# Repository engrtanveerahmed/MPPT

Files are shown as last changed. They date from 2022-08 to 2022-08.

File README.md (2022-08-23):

# Maximum Power Point Tracking (MPPT)

## Introduction
We know that sun light is varriable during day some time is low some time it's intensity is high specially at mid of day its intensity is high due to this our solar pannel gives varriable voltages we intensity is high our normal solar pannel 12 voltes rated  gives 14or 15 voltages and if it is connected to 12v rated bettery this extra voltages is really hazerd for our bettry in ordr to remove this hazerd we design Maximun power point trackin solar charge controller (MPPT).

## Design requirements
In todays world design in project play inportant it requires to main key parameters one is we can carry it any where easily number two it is eye catching, in order to do we made design on autocade and also we are blessed with fablab that contain 3D printer with help of that we made our 3D design

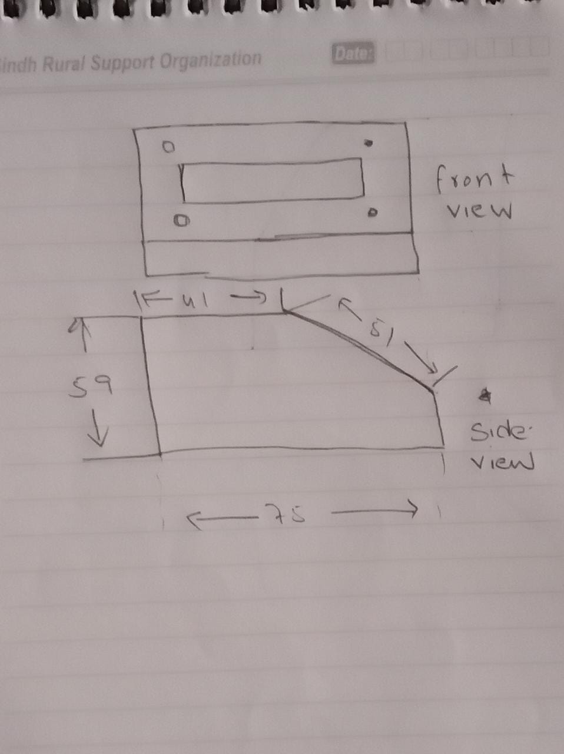
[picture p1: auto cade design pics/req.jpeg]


## Project excuting plan
We have distribute our task in to two member so that beacause in short time we have alot of work to do bellow chart contain our flow of doing work. 

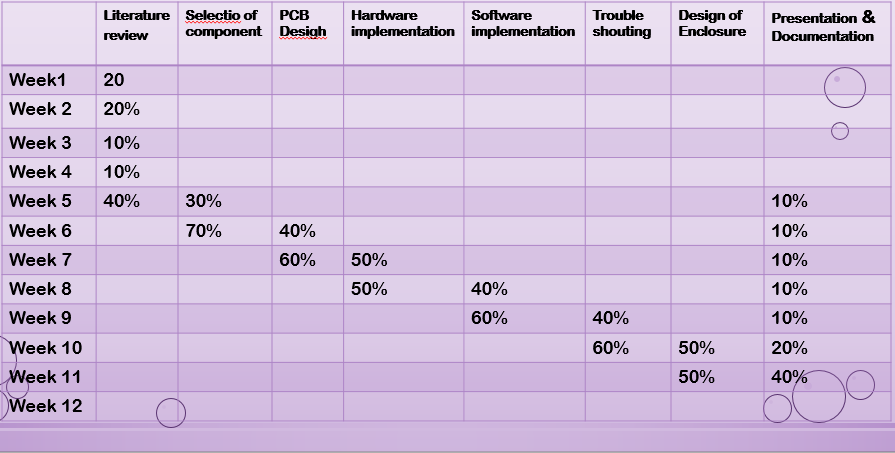
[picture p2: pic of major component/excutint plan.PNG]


## Destributinsion of tasks

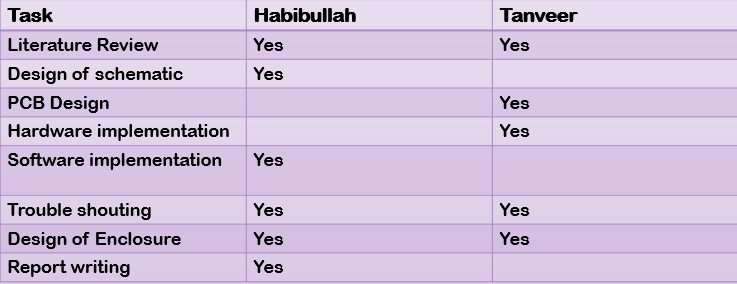
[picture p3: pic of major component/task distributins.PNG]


## Higher level Diagram

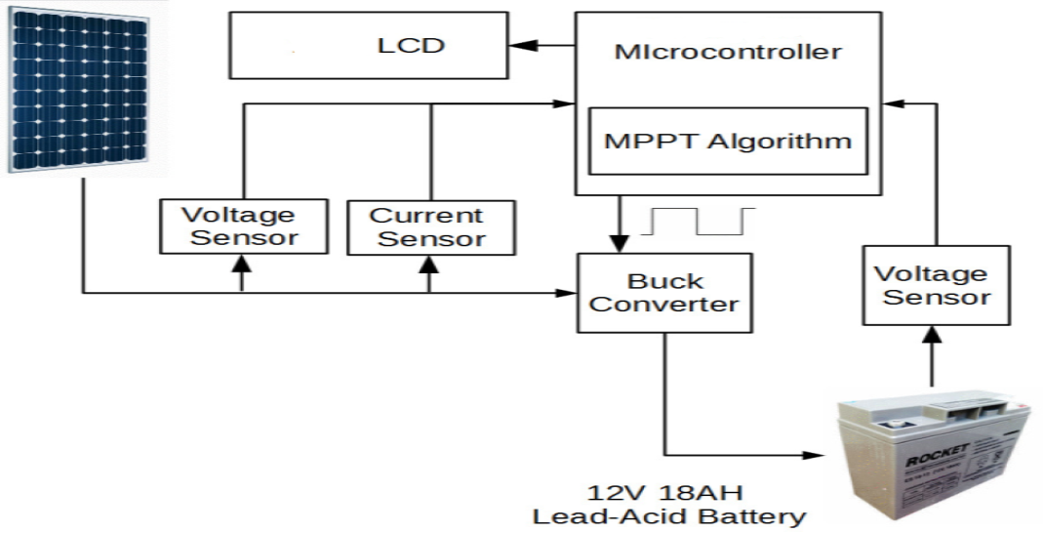
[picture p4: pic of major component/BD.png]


## Description of Principle of Operations
MPPT Min work is to gives stable (12)voltageg at out put this work (step down) is done by the buck converter, at in put and out we used voltage and current sensior; voltages divder circuit at input and output Which sensed voltages developed on the input and gives it to an analogue pin of microcontroller. also a current sense amplifier is attached using a shunt resistor on the main input section. There is also a voltage divider circuit on the output section where the battery is connected. A current sense amplifier is used on the output section as well. These all values are fed to the microcontroller. Depending upon these values, microcontroller decides about the PWM signal fed to the Half-Bridge Mosfet Driver IC. this IC takes input as a PWM signal and switches the MOSFETs with a very high speed. The Buck converter acts according to the decission made by microcontroller depending upon the input and output currents and voltages.

## Bill of material
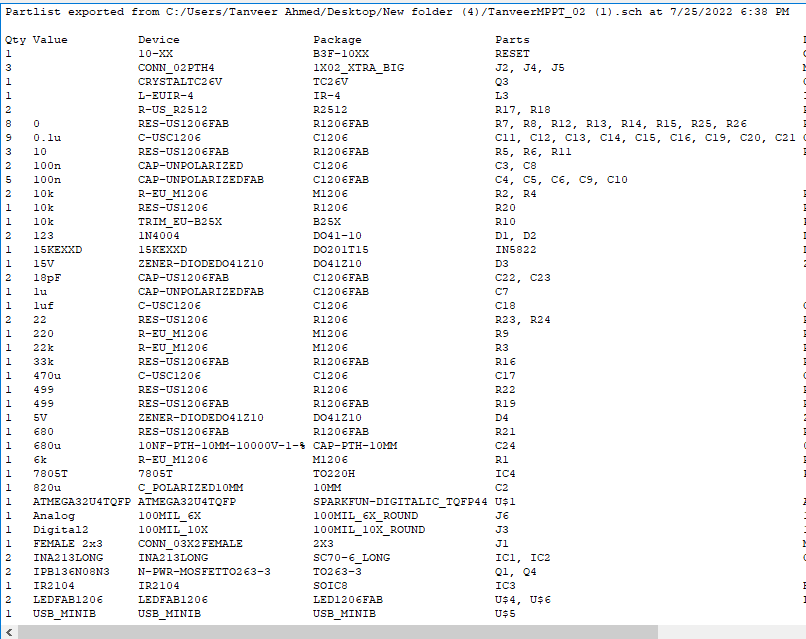
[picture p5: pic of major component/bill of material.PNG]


## Desciption of Major Components of project
##### Microcontroller:

The low-power Microchip 8-bit AVR RISC-based microcontroller featuring 32KB self-programming flash program memory, 2.5KB SRAM, 1KB EEPROM, USB 2.0 full-speed/low speed device, 12-channel 10-bit A/D-converter, and JTAG interface for on-chip-debug. The device achieves up to 16 MIPS throughput at 16 MHz. 2.7 - 5.5 Volt operation. We have used this microcontroller because of its lower consemption and usb support. its features helped us to replace arduino with this microcintroller in project.
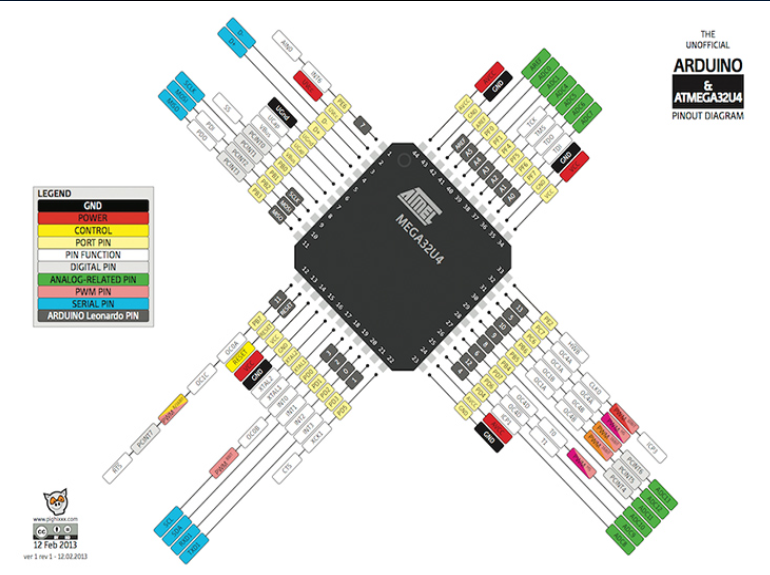
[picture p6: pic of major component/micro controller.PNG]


###### USB mini:
The small USB is used in digitil devices like digital cameras, external hard drives, USB hubs and other equipment. Mini USB is much smaller than USB Type A and B but twice as thick as Micro USB. We have used this componant as we could burn our code easily on the microcontroller.

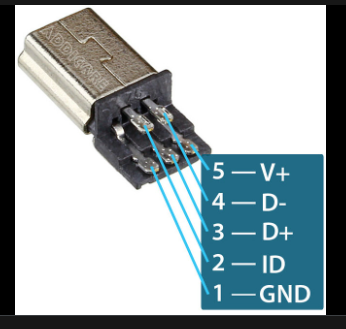
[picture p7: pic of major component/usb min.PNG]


##### INA213 (Current sense amplifier):
The INA21x are voltage-output, current-shunt monitors (also called current-sense amplifiers) that are commonly used for overcurrent protection, precision-current measurement for system optimization, or in closed-loop feedback circuits. This series of devices can sense drops across shunts at common-mode voltages from 0.3 V to 26 V, independent of the supply voltage. Six fixed gains are available: 50 V/V, 75 V/V, 100 V/V, 200 V/V, 500 V/V, or 1000 V/V. The low offset of the zero-drift architecture enables current sensing with maximum drops across the shunt as low as 10-mV full-scale. These devices operate from a single 2.7-V to 26-V power supply, drawing a maximum of 100 uA of supply current. All versions are specified over the extended operating temperature range (40°C to +125°C), and offered in SC70 and UQFN packages. We have used this componant as to sense the input and output voltage/current to track the working of the MPPT.

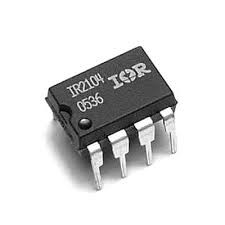
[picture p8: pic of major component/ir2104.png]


##### IR2104 (Half-bridge):
The discrete Half-bridge driver based on IR2104 gate driver IC and low impedance high current N channel IRFP4368 MOSFETS , The IR2104 is a high voltage, high speed power MOSFET driver with independent high and low side referenced output channels. We have used this componant to derive the mosfets.



##### Schottky Diode :
The Schottky Diode is a type of semiconductor diode which have the advantage that their forward voltage drop is substantially less than that of the conventional silicon pn-junction diode. Schottky diodes have many useful applications from rectification, signal conditioning and switching, through to TTL and CMOS logic gates due mainly to their low power and fast switching speeds.

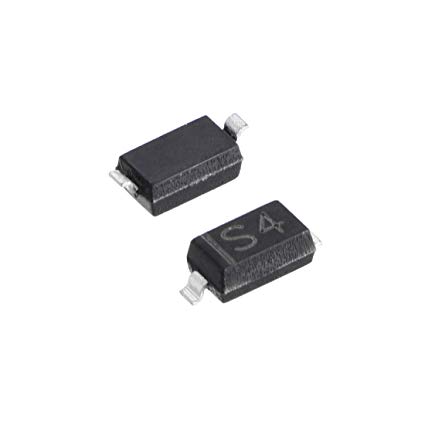
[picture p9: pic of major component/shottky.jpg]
)

##### IPB136n08n3 (PWR-MOSFET):
These are ideal for high frequency switching. Optimized technology for DC/DC converters. Excellent gate charge x R product N-channel, normal level. 100% avalanche tested. Pb-free plating; RoHs compliant.

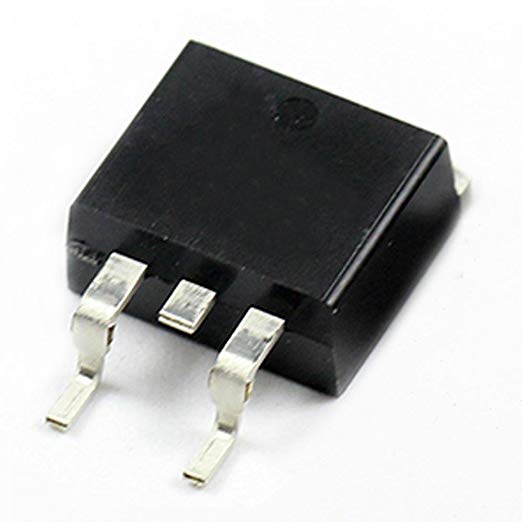
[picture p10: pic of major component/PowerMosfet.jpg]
)

Shunt Resistors:
Shunt resistors are used with current sense amplifier to sense the current.

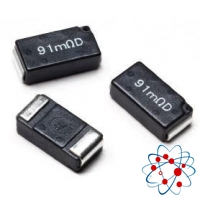
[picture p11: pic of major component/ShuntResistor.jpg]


##### Voltage Regulator LM7805:
We are using this voltage regulator because the input voltage is 12 voltages and our microcintroller and some other componants run on 5V so its is regulating the voltages. It is easily available for use.

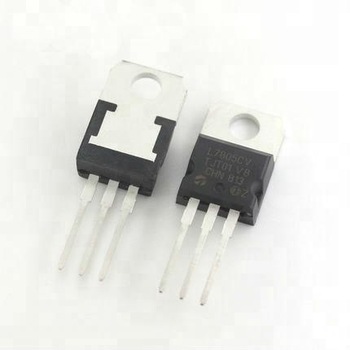
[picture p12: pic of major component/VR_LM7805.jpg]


##### Zener Diode::
We are using zener diode if our input voltage increases from the circuit limitations, it will directly ground the voltages.

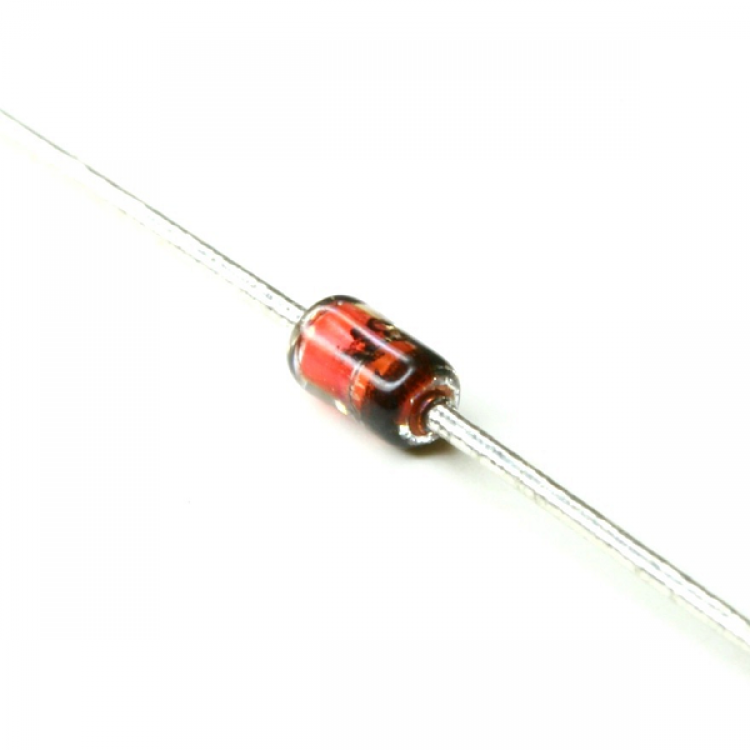
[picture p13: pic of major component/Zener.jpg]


###### Connectivity to components (Protocol)
As we have used Atmega32U4 microcontroller, which has the support to connect a USB, so we are using Universal serial bus for the connectivity of our board with PC to burn the code into it.
## Electrical Schematic
The schematic diagram is taken from the Eagle file we have developed for our final PCB:

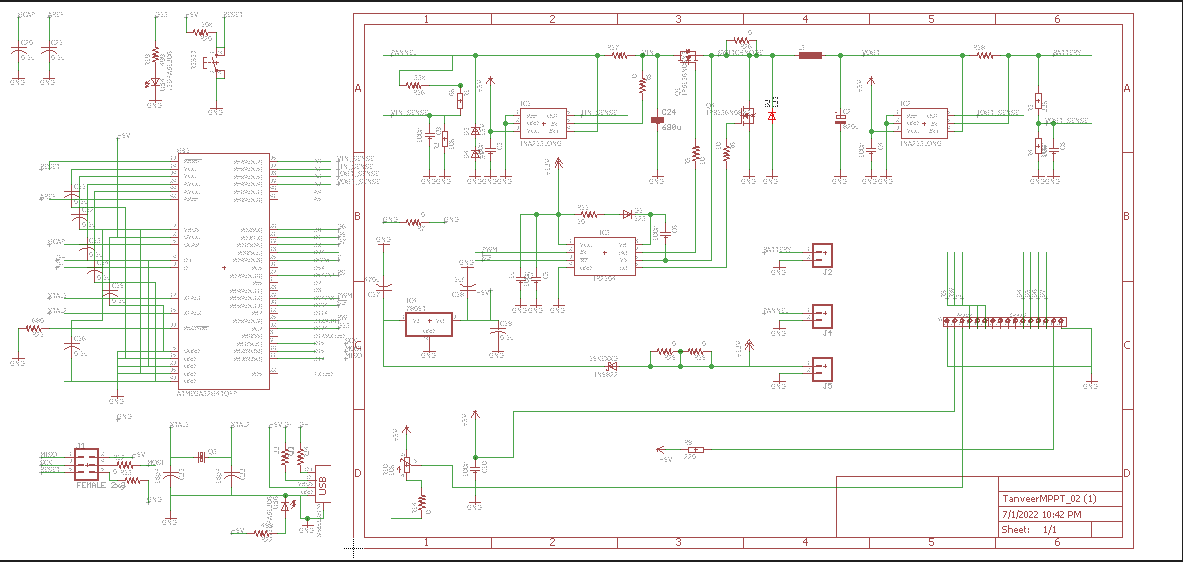
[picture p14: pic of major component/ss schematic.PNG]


## Brief Description of Schematic
Here we define our project more clearily.

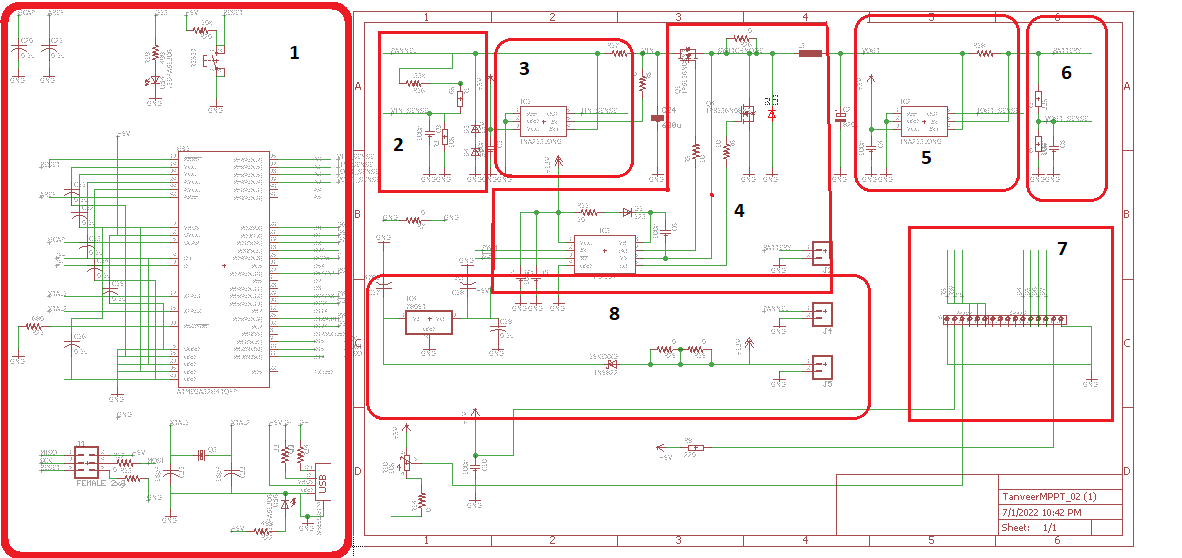
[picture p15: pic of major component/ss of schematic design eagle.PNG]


##### Microcontroller and its required components:
The microcontroller is the key component of this whole circuit as it is making decissions on the basis of values it is receiving. the components attached with microcontroller in "1" are chosen according to the Arduino Leonardo which uses the same Microcontroller. An ICSP header is also connected to burn the boadloader on to the microcontroller. The connection of a USB MINI are also made with the microcontroller.

##### Input Voltage Divider Circuit:
This circuit divides the input voltage to such a level in which microcontroller can sense it because if we attach the microcontroller directly, it cannot bear the voltage and will burnout intantly. So we have to reduce the voltage to such a level which can be given to microcontroller. We used a 39kiloohm resistor and a 10 kilo ohm resistor to make the ratio appropriate. Also two zener voltages are connected in parallel for we want input voltage not more than a certain value.
##### Input Current Sense Amplifier:
INA213, a current sense amplifier is connected here to sense the input current. The shunt resistor helps this IC to sense the current and then this IC gives output to the Microcontroller which then displays it on the LCD.

##### Half Bridge Driver IC and Buck Converter:
The IR2104, a half bridge MOSFET driver takes input of PWM signal from the microcontroller and then performs the switching of the MOSFETs. Hence controlling the output current and voltage.

##### Output Current Sense Amplifier:
It works on the same principle as the input current sense amplifier.

##### Output Voltage Regulator:
Volatge regulator is developed here for the same reason, the only difference is the voltage for division. Here the voltage is 12V. So, we connected a 22 kilo-ohm resistor in series with a 10 kilo-ohm resistor.

##### LCD connectors:
these connectors are attached for the display which will be mounted on the casing.

##### Power Headers and Voltage Regulator:
The three headers for 12 volts Supply(on which the board will operate), Panel(to take input from solar panel) and Output(for the output voltage taken from the circuitry ). The voltage regulator is connected because we are using 12V supply on which the IC IR2104 operates but all other ICs need 5V to operate so we are using this LM7805 for this purpose.

## PCB Layout

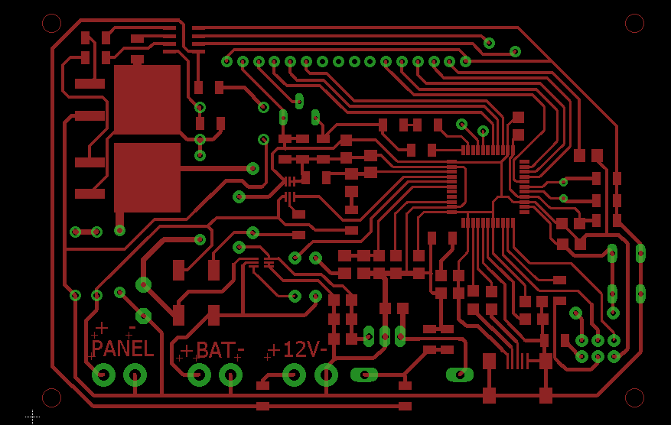
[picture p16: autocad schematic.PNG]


We used Eagle software to develop the PCB for our project and we created the layouts in .PNG formats as the Milling Machine available in Fablab needs picture format for its processing. Following is the final PCB layout:

## Challenges While Routing
Whille routing the PCB it consumed a lot of out time because the circuit we were following used a separate board for microcontroller but our aim was to embed both the circuit on a single layer, making it more compact. This came with lots of hurdles while routing, we used few zero ohm resitor to overcome routing issues and at the end developed a lot more compact circuit after tens of attempts.

## Bill of Material on taped on a Paper
Following is the Picture of the components taken from the FabLab



## Picture of Clean Printed Circuit Board
For fabrication of our PCB, we used SRM-20(Rolland's mills) machine. It needs a monochrome picture for its processing. the monochrome picture we took from Eagle software were then uploaded to the "Fab-Modules.org" and then we generated the ".rml" files needed for SRM-20 to process the milling.

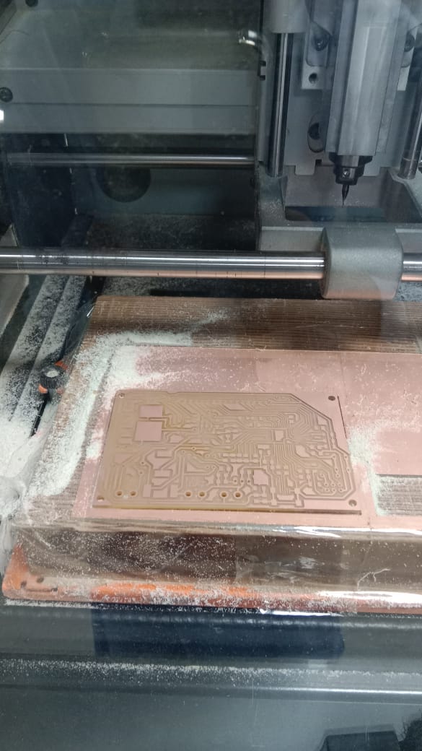
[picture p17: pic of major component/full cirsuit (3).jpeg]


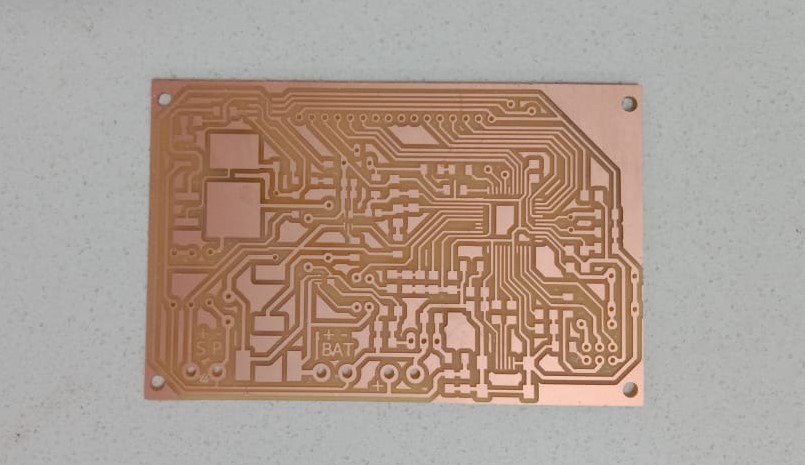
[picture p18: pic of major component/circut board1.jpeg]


## Picture of Populated Circuited Board
After fully soldering teh components, our board looked like this:

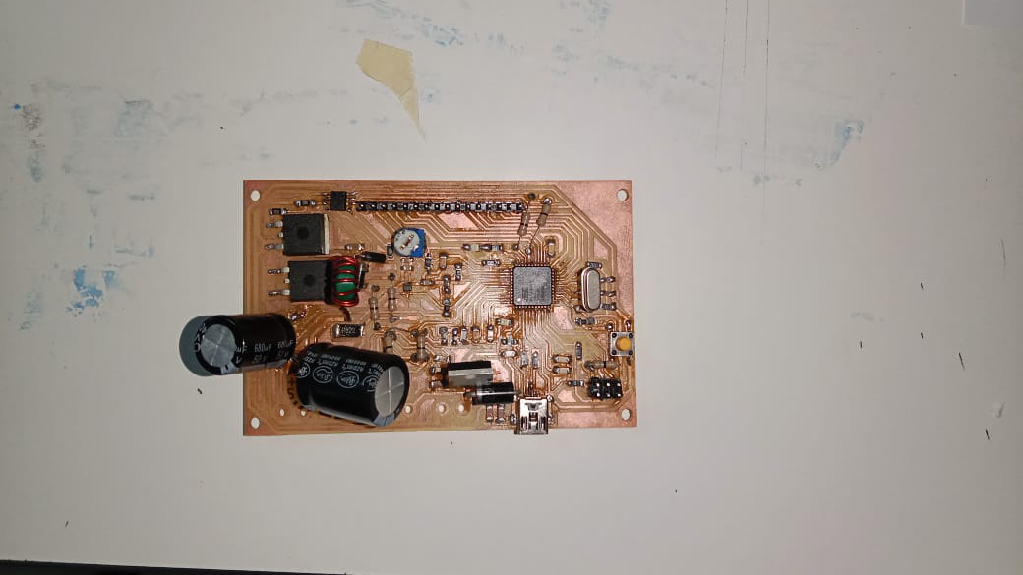
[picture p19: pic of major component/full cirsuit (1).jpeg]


## Procedure adopted to burn Bootloader
To burn the boot loader on to the microcontroller, we used ICSP header and arduino IDE. we burnt the bootloader of Arduino leonardo onto the ATmega32U4. For this we followed the following steps:
1. connetcing th board with PC through ICSP header and a USB mini cable for further burning the test code.
2. selecting the board through "Tools" menu.
3. in tools, further going to submenu "Select Board".
4. selecting "Arduino Leonardo".
5. again going to "tools" menu and then selecting the submenu "Port" and then select the port on which ICSP is connected.
6. again going to another submenu "Programmer" and selecting "AVRISP mkll" .
7. last step is to select the last most option of "burn the bootloader".
8. wait for few minutes till it shows the message on status bar as "Done burning Bootloader.".

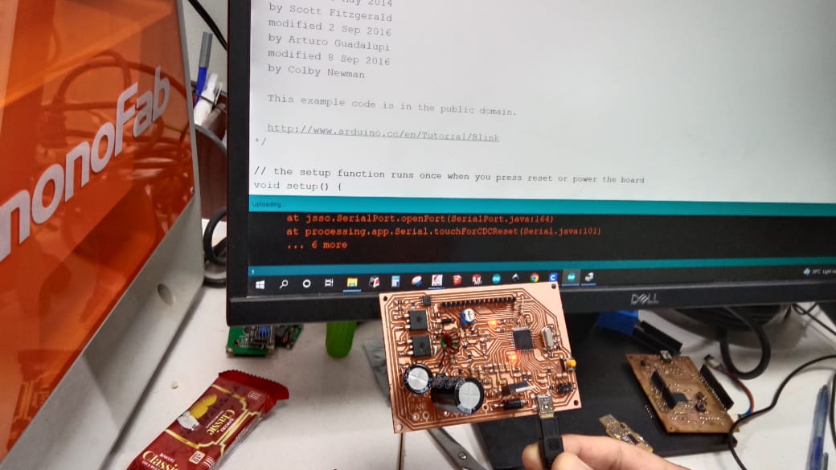
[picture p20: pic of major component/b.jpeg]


## Picture of successfully operating circuit

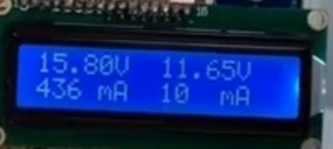
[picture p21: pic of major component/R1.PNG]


## Picture of fully assembled System

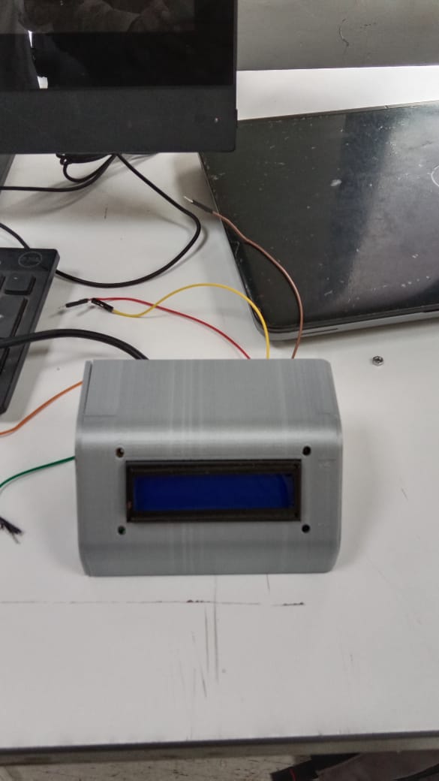
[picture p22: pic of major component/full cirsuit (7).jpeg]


## The FlowChart of our software design

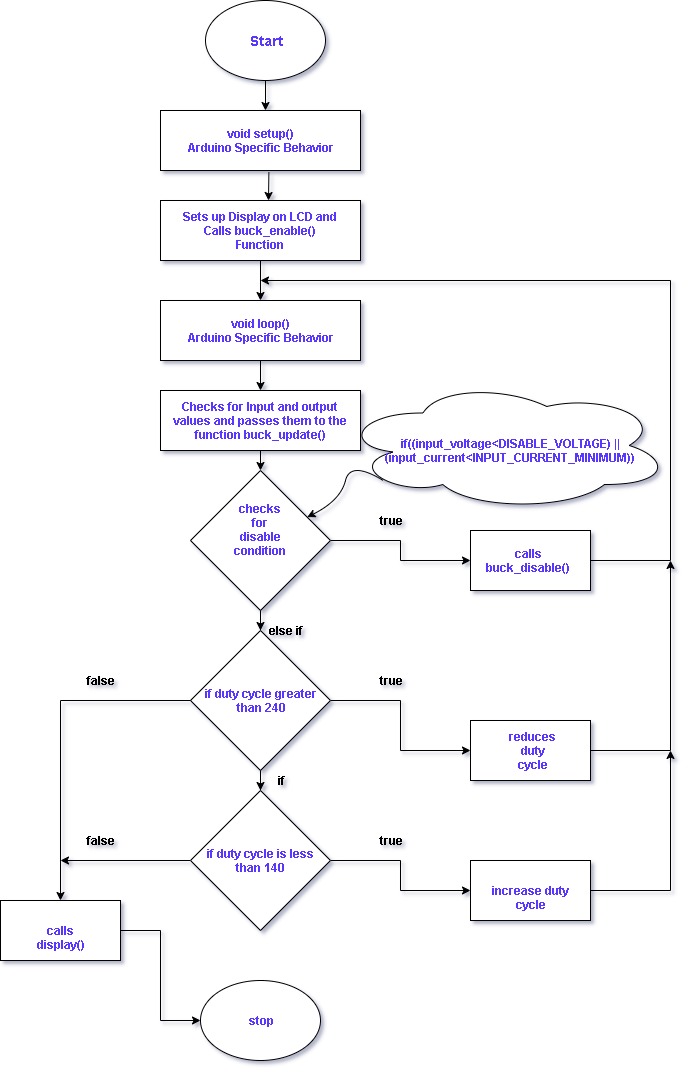
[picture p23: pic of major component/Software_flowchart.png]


## Main Functions of the code
##### buck_setup() Function::
This function is designed to set up the timer to generate PWM signal. It initializes the timer with the desired duty cycle to set the circuit up.
##### buck_enable() Function:
This method is written so to enable the clock source and then turns on the Half bridge driver through PWM signal.
##### buck_disable() Function:
TThis functtion turns off the clock source and sets the duty cycle of PWM signal to zero.
##### buck_duty(unit8_t duty) Function:
This function checks the duty cycle of the and stes it to the appropriate value for the operation of the Buck converter. it Arranges the duty cycle to an optimum level.
##### write_display() Function:
This function is utlized to write on the LCD. it tfakes values from several values and displays them along with some text on the LCD.
##### read_values() Function:
This function takes the values from the volatge divider circuits and current sense amplifiers and sets them correctly after callibration.
##### buck_update() Function:
This method is the key function in the code which calls some of the above functions and updates the duty cucle accordingly.

## Challenges faced while coding
The major problem we faced during the coding for this project was configuring the timer for generatng PWM signal. We tried to configure different available timers using different PWM pins on the board. First we configured timer1 using PWM pin 9, but this timer was a 16 bit timer which brought a lot of problems because our major calculations were based on the 8 bit timer. so after struggling a lot we obtained a maximum volatge of 7.44V at the output. Furthermore we connected our Half bridge driver with PWM pin 11 and using timer0 we obtained the exact output.

## CAD Design of Enclosure
For Casing of our prodcut, we used both laser Cut and 3D-printing. We wanted to consume lesser filament for 3D-printing thats why we thought of making the top of the casing clear to make it a bit unique. So, we made the top using laser cut. We designed a locking mechanism of Slide and press. We slide one side of the top and press the other towards the bottom.

## CAD Design with Dimensions
Followings are the CAD design pictures with dimensions:

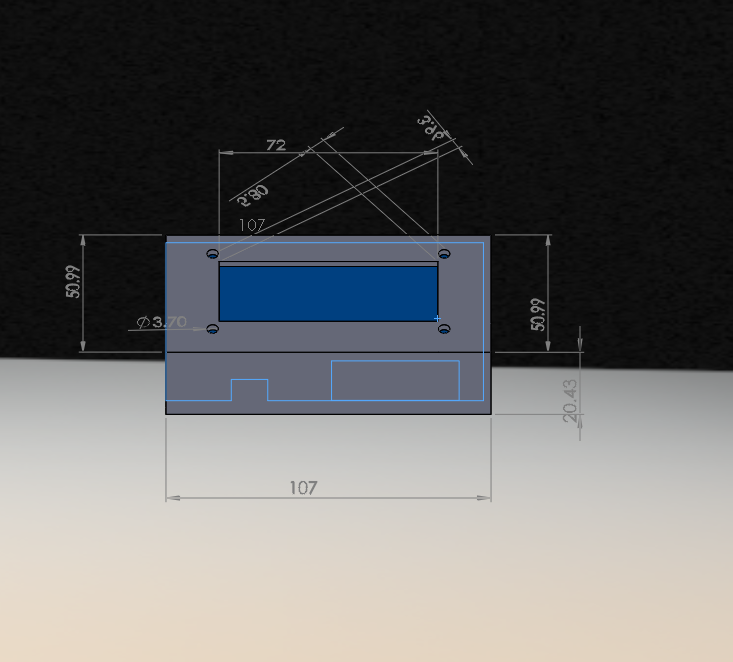
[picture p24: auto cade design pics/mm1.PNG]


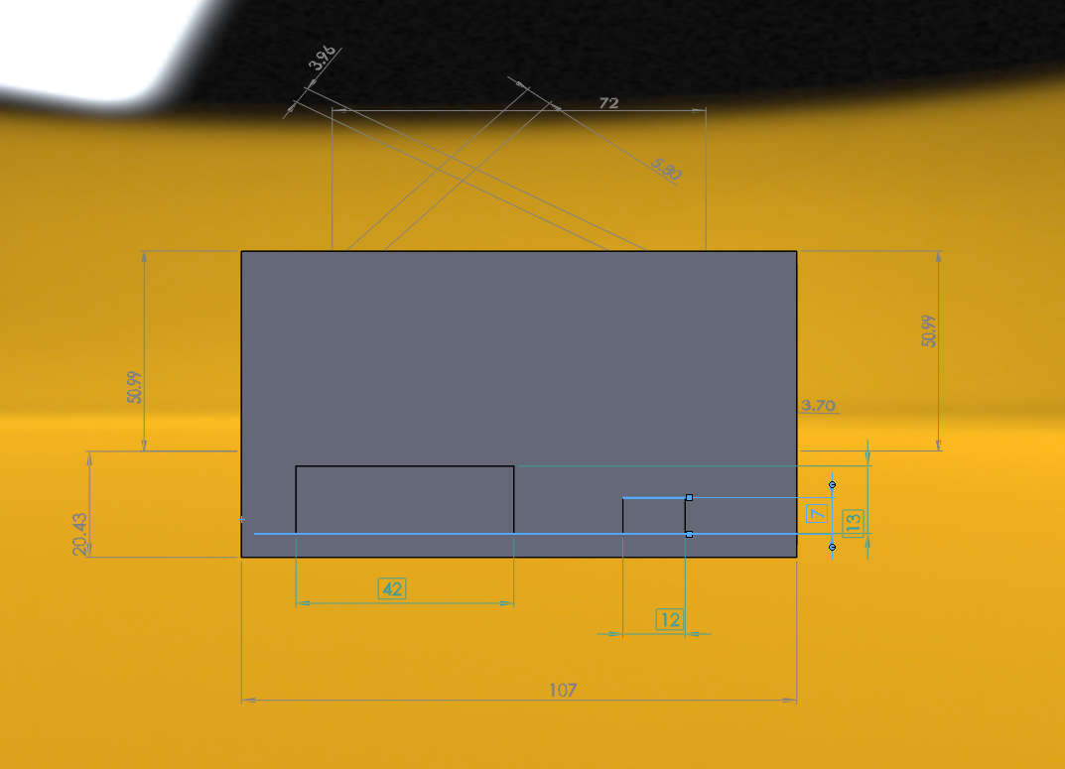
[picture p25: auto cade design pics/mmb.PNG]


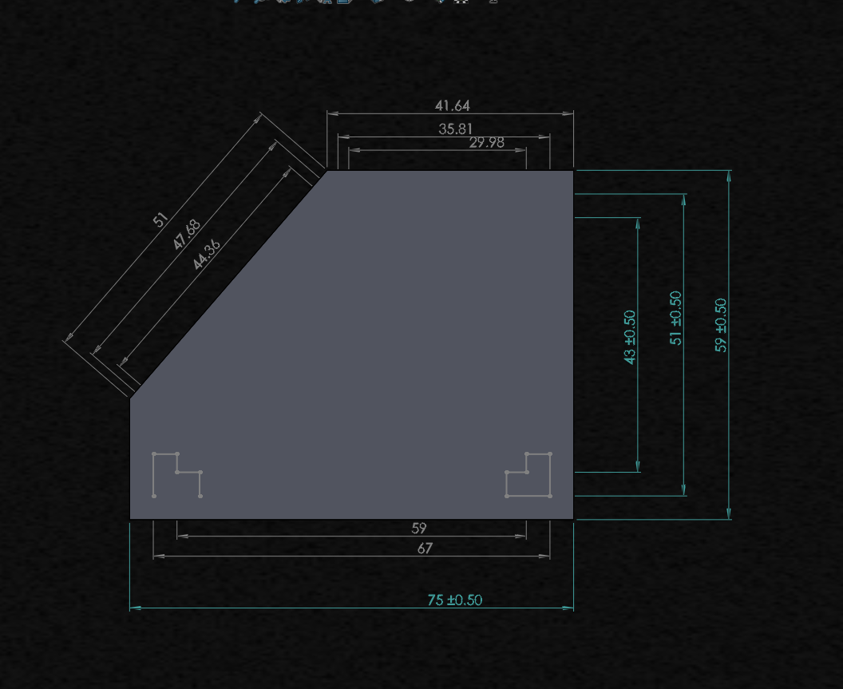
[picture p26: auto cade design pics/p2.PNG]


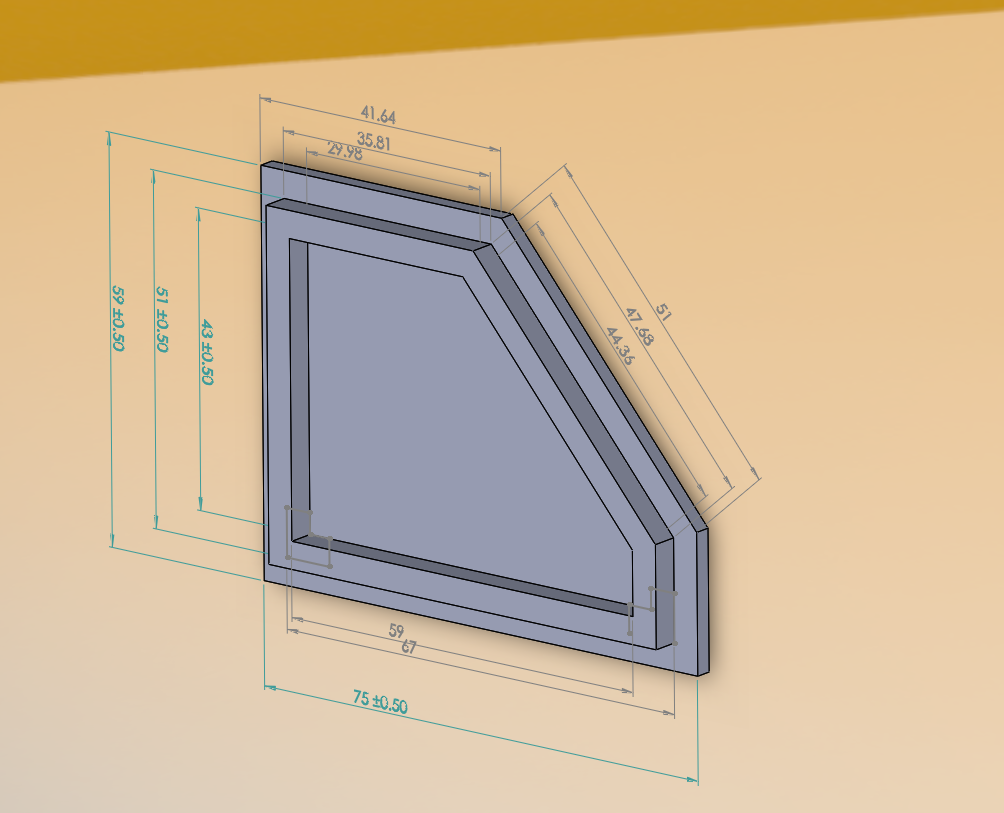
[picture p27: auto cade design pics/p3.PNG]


## Business model

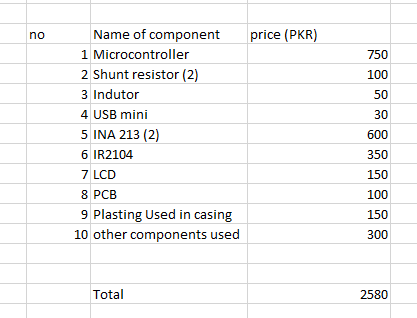
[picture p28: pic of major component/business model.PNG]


Every product which needs to be in the market requires a good business plan. for our product, we considered few major point regarding its cost and its users. As our project is user friendly in terms of its size, the size increases the durability. One can carry it anywhere to be used. Furthermore, solar charges(MPPT based) are very expensive products, we used such components which are commonly available and are cheap. With these two major advantages, we hope to cover a good number of users of our products when released in the market.

## References

[soldernerd web site link review](https://soldernerd.com/2016/01/21/arduino-mppt-solar-charger-shield/)

[Basics of MPPT Solar Charge Controller](http://www.leonics.com/support/article2_14j/articles2_14j_en.php)

[AVR-ATmega16U4-32U4_Datasheet](http://ww1.microchip.com/downloads/en/DeviceDoc/Atmel-7766-8-bit-AVR-ATmega16U4-32U4_Datasheet.pdf)

[Leonardo Timer trouble…](https://forum.arduino.cc/index.php?topic=125252.)

[Tanveer Ahmed (Stutentof Sukkur IBA University, Pakistan)](https://github.com/engrtanveerahmed)

[MPPT Autocade Design file](https://github.com/engrtanveerahmed/MPPT/tree/main/Autocade%20design%20file)

[Mppt Eagle file](https://github.com/engrtanveerahmed/MPPT/tree/main/Eagle%20file)

[Mppt Audino Source Code file](https://github.com/engrtanveerahmed/MPPT/tree/main/source%20code/SolarPanelchk)

## Conclusion
This project was full of learning.We made PCB cricuit three time, the reanson in first board our USB mini port beacme short while sodering because the have small pins we learnt that do soldering carifully a single mistake can distured whole PCB, we made a seconde PCB this time we do soldering care fully but our circuit became short beacuse circuit is large so for this we check continuity test but it work was really time consuming because circuit is large finally we made last circuit it works our pervious PCB boards don not go weste we leart alot from them,but this not good practice because material goes weste we need do things carefully while making eagle file Dia of SRM matchune when it comes to microcontroller, soldering selection of component like we add big capactor which consume whole size of our PCB, We had a lot of practical interaction with our theoratical knowledge. This project proved a golden oppurtunity as we implemented most of our theoratical knowledge.Milling a PCB, designing an enclosure.etc. all of these experiences proved fruitful in increasing our skills and capabilty to do experiments and troubleshooting. In future, we have decided to continue such kind of practice for further learning and skill development.

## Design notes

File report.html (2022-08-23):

# Introduction to Embedded system (Project Report)

### Tanveer Ahmed (033-20-0030) Habibullah (033-20-0026)

## Maximum Power Point Tracking

1 / 6



Caption Text

2 / 6



Caption Two

3 / 6



Caption Three

4 / 6



Caption Four

5 / 6



Caption Five

6 / 6



Caption Six

Introduction

We know that sun light is varriable during day some time is low some time it's intensity is high specially at mid of day its intensity is high due to this our solar pannel gives varriable voltages we intensity is high our normal solar pannel 12 voltes rated gives 14or 15 voltages and if it is connected to 12v rated bettery this extra voltages is really hazerd for our bettry in ordr to remove this hazerd we design Maximun power point trackin solar charge controller (MPPT) . Maxime dicta repellendus eum eos possimus inventore beatae molestiae optio, est consequuntur nam consequatur, vel veritatis corporis velit. Odit eligendi quibusdam mollitia.



Design requirements

In todays world design in project play inportant it requires to main key parameters one is we can carry it any where easily number two it is eye catching, in order to do we made design on autocade and also we are blessed with fablab that contain 3D printer with help of that we made our 3D design.

 

Project excuting plan

We have distribute our task in to two member so that beacause in short time we have alot of work to do bellow chart contain our flow of doing work.



Destributinsion of task



Higher level Diagram



Description of Principle of Operations

MPPT Min work is to gives stable (12)voltageg at out put this work (step down) is done by the buck converter, at in put and out we used voltage and current sensior; voltages divder circuit at input and output Which sensed voltages developed on the input and gives it to an analogue pin of microcontroller. also a current sense amplifier is attached using a shunt resistor on the main input section. There is also a voltage divider circuit on the output section where the battery is connected. A current sense amplifier is used on the output section as well. These all values are fed to the microcontroller. Depending upon these values, microcontroller decides about the PWM signal fed to the Half-Bridge Mosfet Driver IC. this IC takes input as a PWM signal and switches the MOSFETs with a very high speed. The Buck converter acts according to the decission made by microcontroller depending upon the input and output currents and voltages.

Bill of material



Desciption of Major Components of project

(1)Microcontroller:

The low-power Microchip 8-bit AVR RISC-based microcontroller featuring 32KB self-programming flash program memory, 2.5KB SRAM, 1KB EEPROM, USB 2.0 full-speed/low speed device, 12-channel 10-bit A/D-converter, and JTAG interface for on-chip-debug. The device achieves up to 16 MIPS throughput at 16 MHz. 2.7 - 5.5 Volt operation. We have used this microcontroller because of its lower consemption and usb support. its features helped us to replace arduino with this microcintroller in project.



click this to visit the data sheet
(https://pdf1.alldatasheet.com/datasheet-pdf/view/241057/ATMEL/ATMEGA32U4.html)

(2)USB mini:

The small USB is used in digitil devices like digital cameras, external hard drives, USB hubs and other equipment. Mini USB is much smaller than USB Type A and B but twice as thick as Micro USB. We have used this componant as we could burn our code easily on the microcontroller.



(3)INA213 (Current sense amplifier):

The INA21x are voltage-output, current-shunt monitors (also called current-sense amplifiers) that are commonly used for overcurrent protection, precision-current measurement for system optimization, or in closed-loop feedback circuits. This series of devices can sense drops across shunts at common-mode voltages from 0.3 V to 26 V, independent of the supply voltage. Six fixed gains are available: 50 V/V, 75 V/V, 100 V/V, 200 V/V, 500 V/V, or 1000 V/V. The low offset of the zero-drift architecture enables current sensing with maximum drops across the shunt as low as 10-mV full-scale. These devices operate from a single 2.7-V to 26-V power supply, drawing a maximum of 100 uA of supply current. All versions are specified over the extended operating temperature range (40°C to +125°C), and offered in SC70 and UQFN packages. We have used this componant as to sense the input and output voltage/current to track the working of the MPPT.

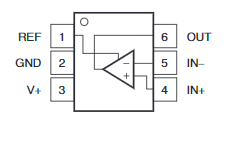
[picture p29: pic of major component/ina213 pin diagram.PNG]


click this to visit the data sheet
(https://pdf1.alldatasheet.com/datasheet-pdf/view/230532/TI/INA213.html)

(4)IR2104 (Half-bridge):

The discrete Half-bridge driver based on IR2104 gate driver IC and low impedance high current N channel IRFP4368 MOSFETS , The IR2104 is a high voltage, high speed power MOSFET driver with independent high and low side referenced output channels. We have used this componant to derive the mosfets.



click this to visit the data sheet
(https://pdf1.alldatasheet.com/datasheet-pdf/view/86635/IRF/IR2104.html)
(5)Schottky Diode :

The Schottky Diode is a type of semiconductor diode which have the advantage that their forward voltage drop is substantially less than that of the conventional silicon pn-junction diode. Schottky diodes have many useful applications from rectification, signal conditioning and switching, through to TTL and CMOS logic gates due mainly to their low power and fast switching speeds.



click below link to dowload the data sheet

click this to visit the data sheet
(https://pdf1.alldatasheet.com/datasheet-pdf/view/544376/KERSEMI/MBR20100CT.html)

(6)IPB136n08n3 (PWR-MOSFET):

These are ideal for high frequency switching. Optimized technology for DC/DC converters. Excellent gate charge x R product N-channel, normal level. 100% avalanche tested. Pb-free plating; RoHs compliant.



click this to visit the data sheet
(https://pdf1.alldatasheet.com/datasheet-pdf/view/544376/KERSEMI/MBR20100CT.html)

(7)Shunt Resistors:

Shunt resistors are used with current sense amplifier to sense the current.



(8)Voltage Regulator LM7805:

We are using this voltage regulator because the input voltage is 12 voltages and our microcintroller and some other componants run on 5V so its is regulating the voltages. It is easily available for use.



click this to visit the data sheet
(https://pdf1.alldatasheet.com/datasheet-pdf/view/85503/ETC/LM7805.html)

(9)Zener Diode::

We are using zener diode if our input voltage increases from the circuit limitations, it will directly ground the voltages.



Connectivity to components (Protocol)

As we have used Atmega32U4 microcontroller, which has the support to connect a USB, so we are using Universal serial bus for the connectivity of our board with PC to burn the code into it.

Electrical Schematic

The schematic diagram is taken from the Eagle file we have developed for our final PCB:



Brief Description of Schematic

Here we define our project more clearily.



(1)Microcontroller and its required components:

The microcontroller is the key component of this whole circuit as it is making decissions on the basis of values it is receiving. the components attached with microcontroller in "1" are chosen according to the Arduino Leonardo which uses the same Microcontroller. An ICSP header is also connected to burn the boadloader on to the microcontroller. The connection of a USB MINI are also made with the microcontroller.

(2)Input Voltage Divider Circuit:

This circuit divides the input voltage to such a level in which microcontroller can sense it because if we attach the microcontroller directly, it cannot bear the voltage and will burnout intantly. So we have to reduce the voltage to such a level which can be given to microcontroller. We used a 39kiloohm resistor and a 10 kilo ohm resistor to make the ratio appropriate. Also two zener voltages are connected in parallel for we want input voltage not more than a certain value.

(3)Input Current Sense Amplifier:

INA213, a current sense amplifier is connected here to sense the input current. The shunt resistor helps this IC to sense the current and then this IC gives output to the Microcontroller which then displays it on the LCD.

(4) Half Bridge Driver IC and Buck Converter:

The IR2104, a half bridge MOSFET driver takes input of PWM signal from the microcontroller and then performs the switching of the MOSFETs. Hence controlling the output current and voltage.

(5)Output Current Sense Amplifier:

It works on the same principle as the input current sense amplifier.

(6)Output Voltage Regulator:

Volatge regulator is developed here for the same reason, the only difference is the voltage for division. Here the voltage is 12V. So, we connected a 22 kilo-ohm resistor in series with a 10 kilo-ohm resistor.

(7)LCD connectors:

these connectors are attached for the display which will be mounted on the casing.

(8)Power Headers and Voltage Regulator:

The three headers for 12 volts Supply(on which the board will operate), Panel(to take input from solar panel) and Output(for the output voltage taken from the circuitry ). The voltage regulator is connected because we are using 12V supply on which the IC IR2104 operates but all other ICs need 5V to operate so we are using this LM7805 for this purpose.

PCB Layout

We used Eagle software to develop the PCB for our project and we created the layouts in .PNG formats as the Milling Machine available in Fablab needs picture format for its processing. Following is the final PCB layout:



Challenges While Routing

Wwhille routing the PCB it consumed a lot of out time because the circuit we were following used a separate board for microcontroller but our aim was to embed both the circuit on a single layer, making it more compact. This came with lots of hurdles while routing, we used few zero ohm resitor to overcome routing issues and at the end developed a lot more compact circuit after tens of attempts.

Bill of Material on taped on a Paper

Following is the Picture of the components taken from the FabLab



Picture of Clean Printed Circuit Board

For fabrication of our PCB, we used SRM-20(Rolland's mills) machine. It needs a monochrome picture for its processing. the monochrome picture we took from Eagle software were then uploaded to the "Fab-Modules.org" and then we generated the ".rml" files needed for SRM-20 to process the milling.





Picture of Populated Circuited Board

After fully soldering teh components, our board looked like this:

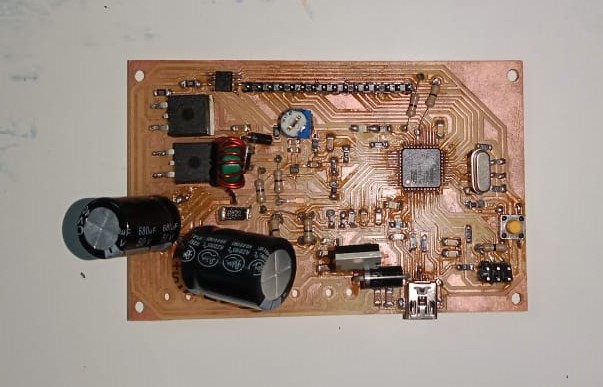
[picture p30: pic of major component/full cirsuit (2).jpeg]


Procedure adopted to burn Bootloader

To burn the boot loader on to the microcontroller, we used ICSP header and arduino IDE. we burnt the bootloader of Arduino leonardo onto the ATmega32U4. For this we followed the following steps:

1- connetcing th board with PC through ICSP header and a USB mini cable for further burning the test code.

2- selecting the board through "Tools" menu.

3- in tools, further going to submenu "Select Board".

4- selecting "Arduino Leonardo".

5- again going to "tools" menu and then selecting the submenu "Port" and then select the port on which ICSP is connected.

6- again going to another submenu "Programmer" and selecting "AVRISP mkll" .

7- last step is to select the last most option of "burn the bootloader".

8- wait for few minutes till it shows the message on status bar as "Done burning Bootloader.".



Picture of successfully operating circuit



Picture of fully assembled System



## Demonstration of operational circuit

## click on below (introdution to MMPT) to watch intodution video of MPPT:

## Introduction Of Mppt

## click on below (MMPT Result ) to watch Results video of MPPT:

## Mppt Results (https://drive.google.com/file/d/1lholKQWcZ44rNQwsQiCtHbxIgZ9bZKCr/view?usp=sharing)

## The FlowChart of our software design

## 

## Main Functions of the code

## (1)buck_setup() Function::

## This function is designed to set up the timer to generate PWM signal. It initializes the timer with the desired duty cycle to set the circuit up.

## (2) buck_enable() Function:

## This method is written so to enable the clock source and then turns on the Half bridge driver through PWM signal.

## (3) buck_disable() Function:

## TThis functtion turns off the clock source and sets the duty cycle of PWM signal to zero.

## (4) buck_duty(unit8_t duty) Function:

## This function checks the duty cycle of the and stes it to the appropriate value for the operation of the Buck converter. it Arranges the duty cycle to an optimum level.

## (5) write_display() Function:

## This function is utlized to write on the LCD. it tfakes values from several values and displays them along with some text on the LCD.

## (6)read_values() Function:

## This function takes the values from the volatge divider circuits and current sense amplifiers and sets them correctly after callibration.

## (7) buck_update() Function:

## This method is the key function in the code which calls some of the above functions and updates the duty cucle accordingly.

## Challenges faced while coding

The major problem we faced during the coding for this project was configuring the timer for generatng PWM signal. We tried to configure different available timers using different PWM pins on the board. First we configured timer1 using PWM pin 9, but this timer was a 16 bit timer which brought a lot of problems because our major calculations were based on the 8 bit timer. so after struggling a lot we obtained a maximum volatge of 7.44V at the output. Furthermore we connected our Half bridge driver with PWM pin 11 and using timer0 we obtained the exact output.

## CAD Design of Enclosure

For Casing of our prodcut, we used both laser Cut and 3D-printing. We wanted to consume lesser filament for 3D-printing thats why we thought of making the top of the casing clear to make it a bit unique. So, we made the top using laser cut. We designed a locking mechanism of Slide and press. We slide one side of the top and press the other towards the bottom.

## CAD Design with Dimensions

## Followings are the CAD design pictures with dimensions:

## 

## 

## 

## 

## Business model

## 

Every product which needs to be in the market requires a good business plan. for our product, we considered few major point regarding its cost and its users. As our project is user friendly in terms of its size, the size increases the durability. One can carry it anywhere to be used. Furthermore, solar charges(MPPT based) are very expensive products, we used such components which are commonly available and are cheap. With these two major advantages, we hope to cover a good number of users of our products when released in the market.

## References

## (1)soldernerd web site link review 1

## https://soldernerd.com/2016/01/21/arduino-mppt-solar-charger-shield/" target 2- http://www.leonics.com/support/article2_14j/articles2_14j_en.php 3- http://ww1.microchip.com/downloads/en/DeviceDoc/Atmel-7766-8-bit-AVR-ATmega16U4-32U4_Datasheet.pdf 4. https://forum.arduino.cc/index.php?topic=125252.0

## (5)Dr. Muhammad Asim Samejo (Assistant Professor at Sukkur IBA University,Pakistan)

## http://www.iba-suk.edu.pk/faculty/details/INS-0011" target

## (6)Engr. Aizaz Ali Larik (Lab Engineer at Sukkur IBA University,Pakistan)

## http://www.iba-suk.edu.pk/faculty/details/INS-0424" target

## (7)Engr. Aizaz Ali Larik (Lab Engineer at Sukkur IBA University,Pakistan)

## http://www.iba-suk.edu.pk/faculty/details/INS-0424" target

## (8)Nadir Ali (Fab Lab Attendant at Sukkur IBA University, Pakistan)

## "nadir.ali@iba-suk.edu.pk" target

## (9)Tanveer Ahmed (Stutentof Sukkur IBA University, Pakistan)

## tanveerahmed.beef20@iba-suk.edu.pk" target

## (10)HabibullH (Stutentof Sukkur IBA University, Pakistan)

## habbibullah.beef20@iba-suk.edu.pk" target

## Contact Us

## Tanveer Ahmed (Undergraduate Electrical Engineering Student at Sukkur IBA University, Pakistan)

## Email: tanveerahmed.beef20@iba-suk.edu.pk

## Contact: +92 303 3005395

## Habibullah (Undergraduate Electrical Engineering Student at Sukkur IBA University, Pakistan)

## Email: habibullah.beef20@iba-suk.edu.pk

## Contact: +92 304 0900929

## Zip file containing 3D Design

## Mppt Auto cade file (https://drive.google.com/drive/folders/13cZIk0gz_pKKPEY3_u3sumELFCERNEMQ?usp=sharing)

## link contain Eagle file

## Mppt Eagle file (https://drive.google.com/drive/folders/1C7_IOqNWIlCzD_C77_IQ-Y8g87hrQthH?usp=sharing)

## Source Code file

## Mppt Audino code (https://drive.google.com/drive/folders/1urthHy6uQ42iCmrYkbOOATOsWzP3bWDY?usp=sharing)

## Conclusion

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

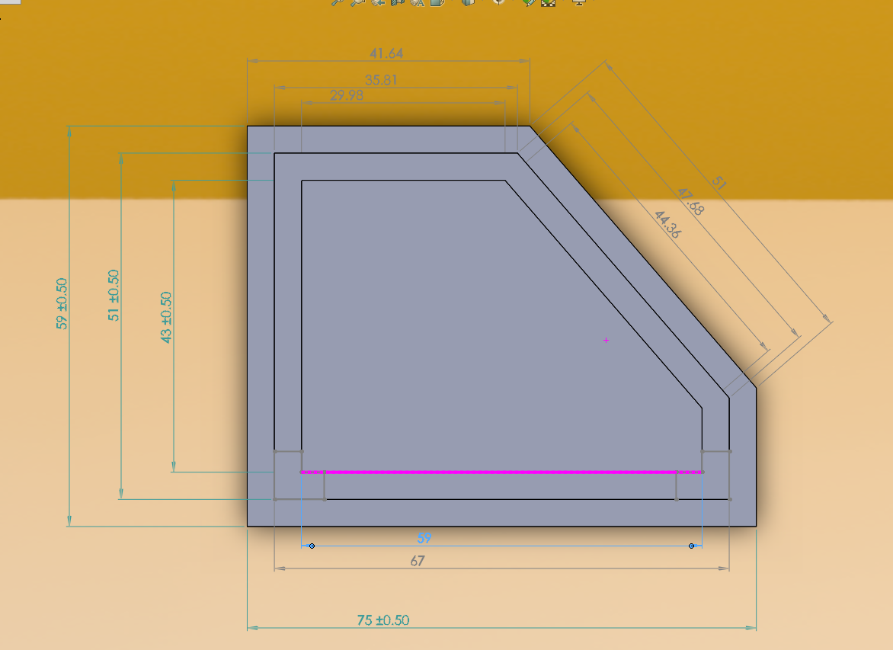
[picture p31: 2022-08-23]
auto cade design pics/Capture.PNG

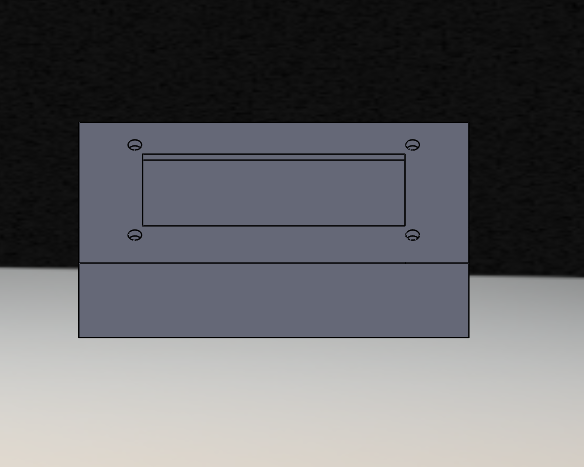
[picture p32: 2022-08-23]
auto cade design pics/a3.PNG

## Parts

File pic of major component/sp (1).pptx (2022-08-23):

## IS THE CPI BEST MEASURE OF INFLATION?

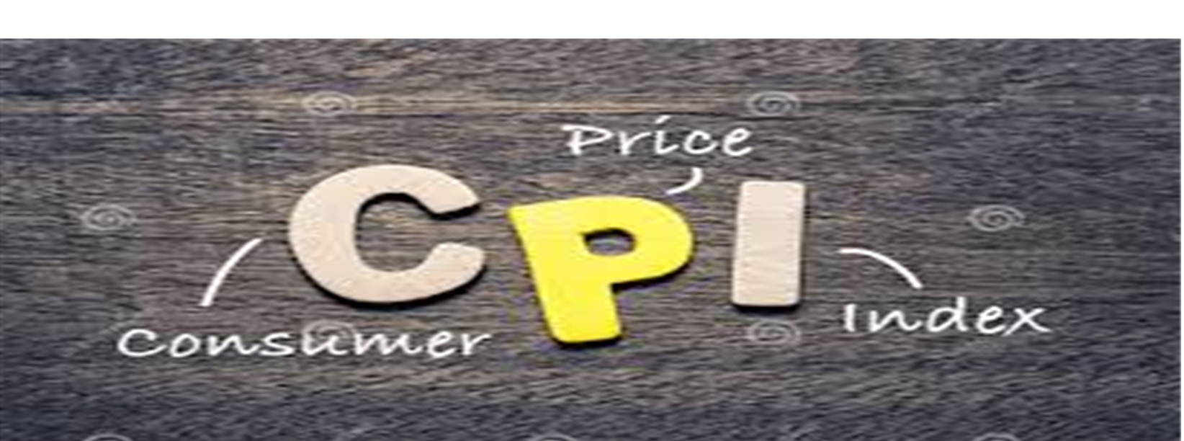
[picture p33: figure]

## PRESENTRS

- Suraj panjwani
- Zamanullah
- Sakshi Karara
- Hira Shaikh
- Sadhori Gopchandani

## INFLATION

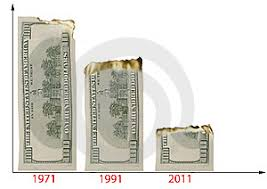
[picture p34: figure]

- Inflation is the percentage increase in the prices of goods and services in a given time period.
- When the prices of an economy rise then overall purchases power of individual got reduced

## Positive impacts of inflation

- Better savings accounts rates
- Cheaper to travel abroad
- Offsets negative effects of deflation
- Wages will be higher
- Get cost of living adjustments

## Negative impacts of inflation

- Low salary
- Low pension
- Lower the value of treasury notes
- Borrowing money is more expensive
- Stuff cost more
- Long term savings might erode

## Whole Sale Price Index

- Definition: It is an indicator that measure the price changes of goods before the retail level. WPI concern with goods that are sold in huge quantity like trade between two businesses.
- Example; Trade between Nikee and Gucci.

## Course Instructor:

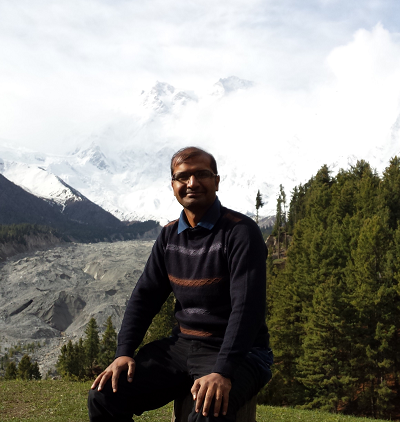
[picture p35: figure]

- Dr.Asim Ali Samejo

## Mr.Tanveer Ahmed

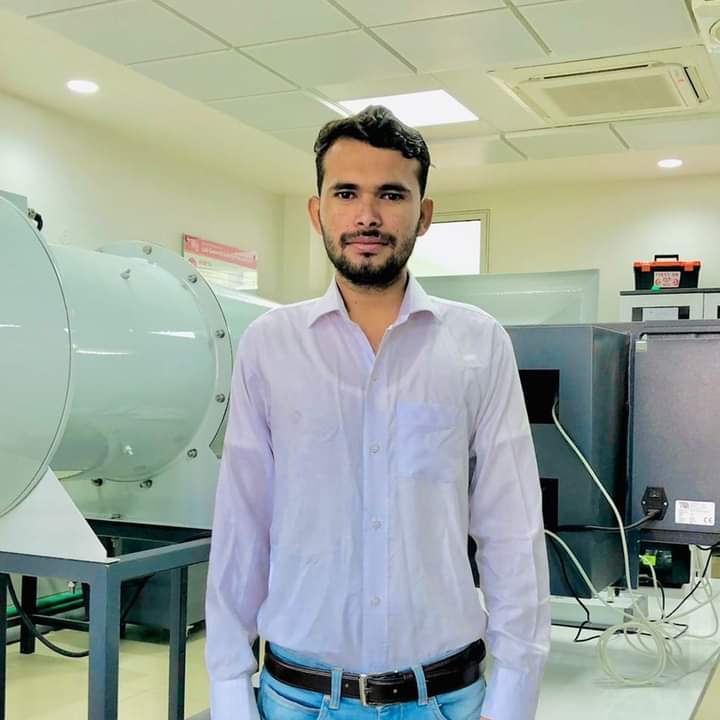
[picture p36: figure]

- Student of Electrical Engineering at Sukkur IBA University
- Semester 4th
- Cms Id:033-20-0030
- Email:tanveerahmed.beef20@iba-suk.edu.pk

## Mr. Habibullah

- Student of Electrical Engineering at Sukkur IBA University
- Semester 4th
- Cms Id:033-20-0026
- E-mail:habibullah.beef20@iba-suk.edu.pk

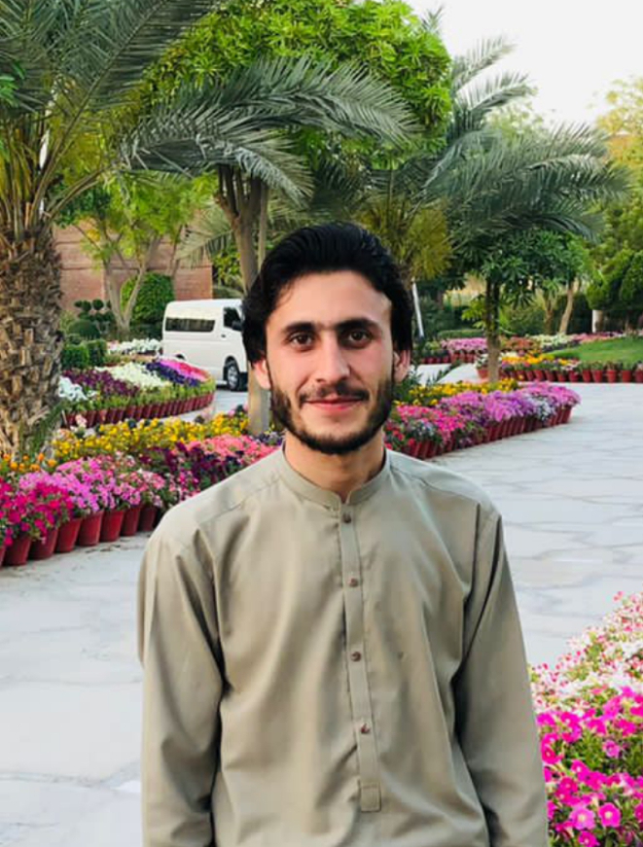
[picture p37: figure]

## Maximum Power Point Controller(MPPT)

NO Yes
No Yes No Yes

Measure
V(k).I(Ik)

Calculate P(K)

P(k)>p(k-1)

V(k)>V(k-1)

V(k)>V(k-1)

Vref=Vref+c

Vref=Vref+c

Vref=Vref-c

Vref=Vref+c

P(k-1)=p(k)

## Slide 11

## Consumer price index

- CPI is used to measure inflation.
- CPI measure the cost of fixed set(basket) consumer goods and services related to cost of same quantity, same goods and services in a base period
- It is the average commodity consumed by a class of people so that they can maintained the same standard of living in the current year to the base year.

## Formula of CPI

- CPI current year = cost of market basket in current period/ cost of market basket in base period

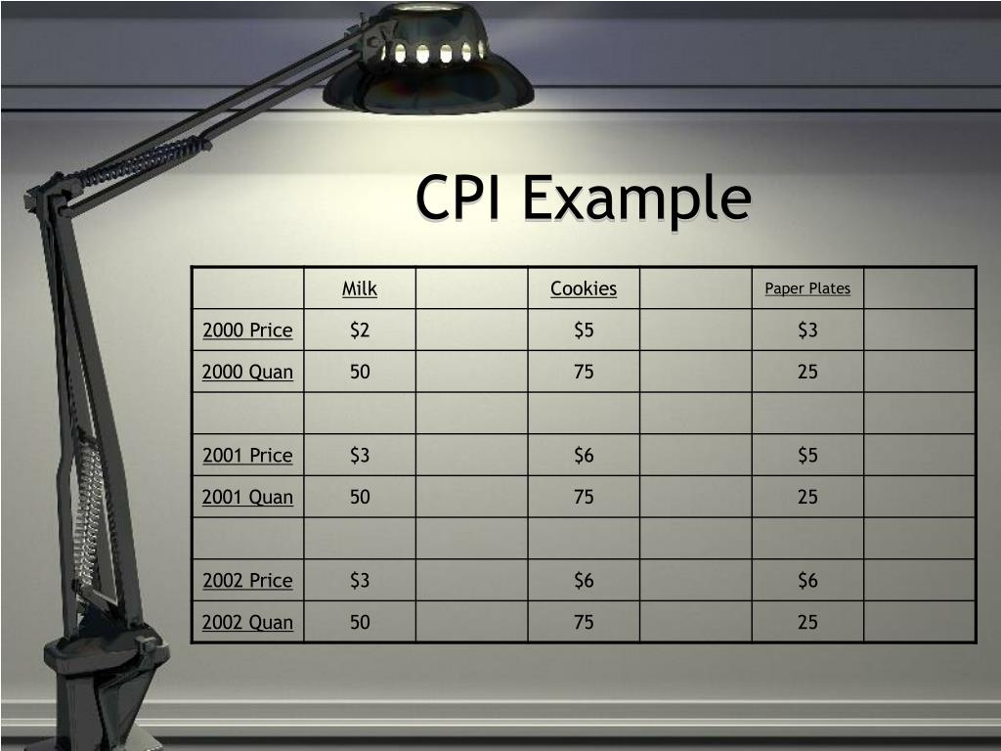
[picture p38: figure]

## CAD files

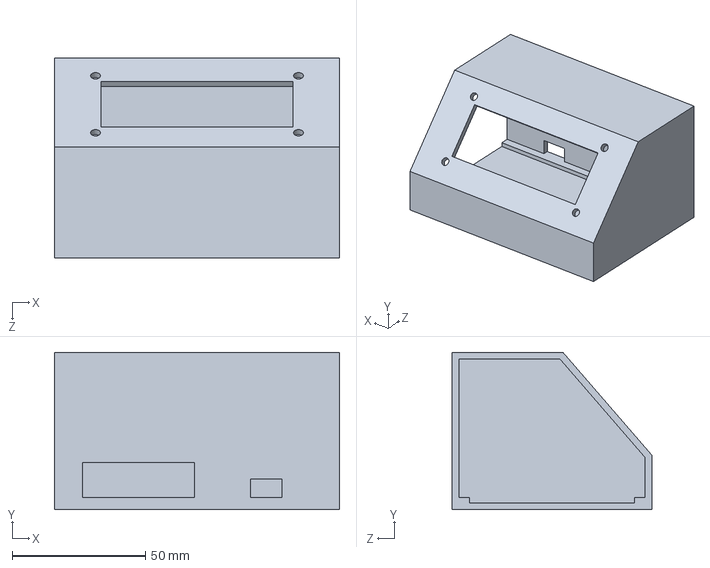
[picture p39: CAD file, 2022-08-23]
Autocade design file/tanveer.SLDPRT
107.0 x 59.0 x 75.0 mm

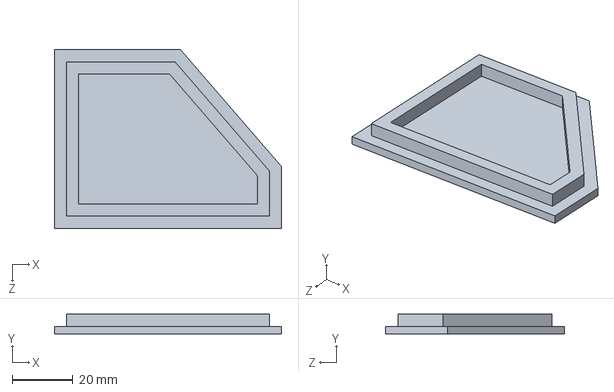
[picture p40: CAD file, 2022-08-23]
Autocade design file/part2 MPPT.SLDPRT
75.0 x 6.50 x 59.0 mm

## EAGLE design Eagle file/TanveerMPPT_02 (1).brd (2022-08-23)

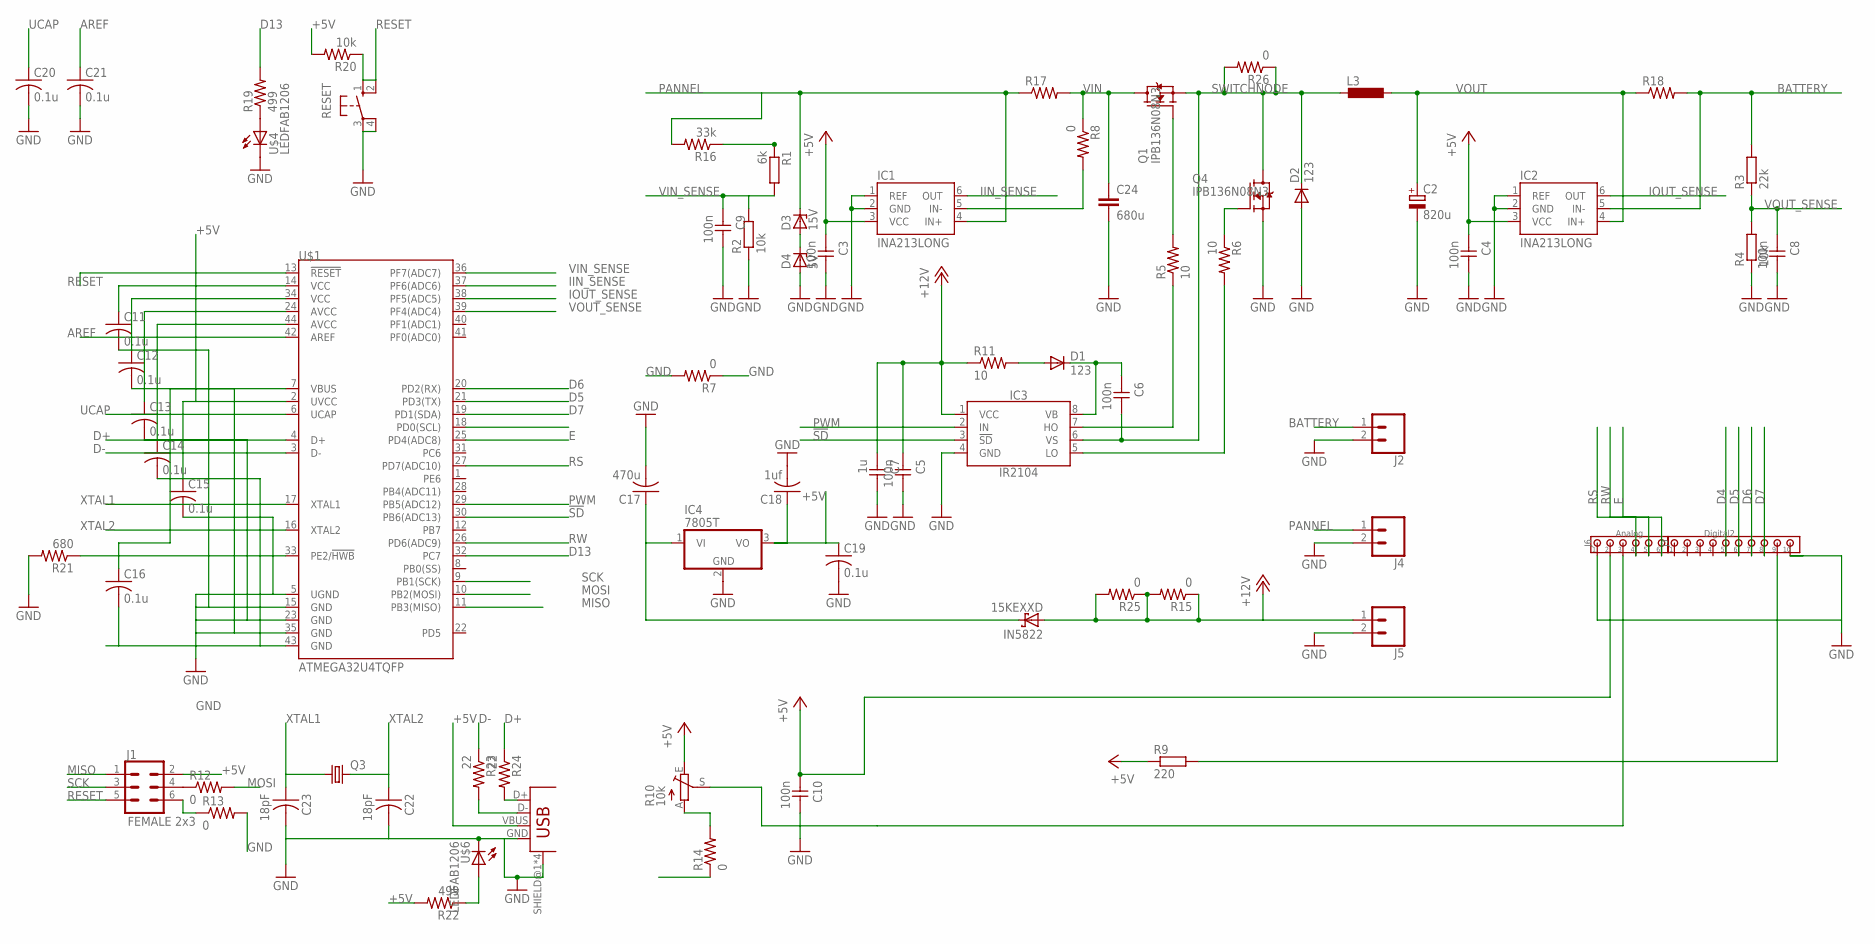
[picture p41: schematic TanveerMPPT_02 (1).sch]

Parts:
C2: 820u; 10MM
C3, C8: 100n; C1206
C4, C5, C6, C9, C10: 100n; C1206FAB
C7: 1u; C1206FAB
C11, C12, C13, C14, C15, C16, C19, C20, C21: 0.1u; C1206
C17: 470u; C1206
C18: 1uf; C1206
C22, C23: 18pF; C1206FAB
C24: 680u; CAP-PTH-10MM
D1, D2: 123; DO41-10
D3: 15V; DO41Z10
D4: 5V; DO41Z10
IC1, IC2: INA213LONG; SC70-6_LONG
IC3: IR2104; SOIC8
IC4: 7805T; TO220H
IN5822: 15KEXXD; DO201T15
J1: FEMALE 2x3; 2X3
J2, J4, J5: CONN_02PTH4; 1X02_XTRA_BIG
J3: Digital2; 100MIL_10X_ROUND
J6: Analog; 100MIL_6X_ROUND
L3: L-EUIR-4; IR-4
Q1, Q4: IPB136N08N3; TO263-3
Q3: CRYSTALTC26V; TC26V
R1: 6k; M1206
R2, R4: 10k; M1206
R3: 22k; M1206
R5, R6, R11: 10; R1206FAB
R7, R8, R12, R13, R14, R15, R25, R26: 0; R1206FAB
R9: 220; M1206
R10: 10k; B25X
R16: 33k; R1206FAB
R17, R18: R-US_R2512; R2512
R19: 499; R1206FAB
R20: 10k; R1206
R21: 680; R1206FAB
R22: 499; R1206
R23, R24: 22; R1206
RESET: 10-XX; B3F-10XX
U$1: ATMEGA32U4TQFP; SPARKFUN-DIGITALIC_TQFP44
U$4, U$6: LEDFAB1206; LED1206FAB
U$5: USB_MINIB

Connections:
!SD!: IC3.3 (!SD!), U$1.30 (PB6(ADC13))
+5V: C3.1, C4.1, C10.1, C11.1, C12.1, C13.1, C14.1, C15.1, C16.1, C18.1, C19.1, IC1.3 (VCC), IC2.3 (VCC), IC4.3 (VO), J1.2, J6.2, R9.1, R10.E, R20.2, R22.2, U$1.2 (UVCC), U$1.7 (VBUS), U$1.14 (VCC), U$1.24 (AVCC), U$1.34 (VCC), U$1.44 (AVCC), U$5.VBUS
+12V: C5.1, C7.1, IC3.1 (VCC), IN5822.A, J5.1, R11.1, R15.1, R15.2, R25.1, R25.2
AREF: C21.1, U$1.42 (AREF)
BATTERY: IC2.5 (IN-), J2.1, R3.2, R18.2
D4: J3.5, U$1.18 (PD0(SCL))
D5: J3.6, U$1.21 (PD3(TX))
D6: J3.7, U$1.20 (PD2(RX))
D7: J3.8, U$1.19 (PD1(SDA))
D13: R19.2, U$1.32 (PC7)
D+: R24.1, U$1.4 (D+)
D-: R23.1, U$1.3 (D-)
E: J6.6, U$1.25 (PD4(ADC8))
GND: C2.-, C3.2, C4.2, C5.2, C7.2, C8.2, C9.2, C10.2, C11.2, C12.2, C13.2, C14.2, C15.2, C16.2, C17.2, C18.2, C19.2, C20.2, C21.2, C22.2, C23.2, C24.2, D2.A, D4.A, IC1.1 (REF), IC1.2 (GND), IC2.1 (REF), IC2.2 (GND), IC3.4 (GND), IC4.2 (GND), J2.2, J3.10, J4.2, J5.2, J6.1, Q4.3 (S), R2.1, R4.1, R7.1, R7.2, R10.A, R13.2, R14.1, R14.2, R21.2, RESET.3, RESET.4 (P1), U$1.5 (UGND), U$1.15 (GND), U$1.23 (GND), U$1.35 (GND), U$1.43 (GND), U$4.2 (C), U$5.GND, U$5.SHIELD@1 (SHIELD), U$5.SHIELD@2 (SHIELD), U$5.SHIELD@3 (SHIELD), U$5.SHIELD@4 (SHIELD), U$6.2 (C)
IIN_SENSE: IC1.6 (OUT), U$1.37 (PF6(ADC6))
IOUT_SENSE: IC2.6 (OUT), U$1.38 (PF5(ADC5))
MISO: J1.1, U$1.11 (PB3(MISO))
MOSI: R12.2, U$1.10 (PB2(MOSI))
unnamed: J1.4, R12.1
unnamed: J1.6, R13.1
unnamed: IC1.5 (IN-), R8.2
unnamed: Q1.1 (G), R5.2
unnamed: Q4.1 (G), R6.1
unnamed: J3.9, R9.2
unnamed: J6.3, R10.S
unnamed: D1.A, R11.2
unnamed: C6.1, D1.C, IC3.8 (VB)
unnamed: IC3.7 (HO), R5.1
unnamed: IC3.5 (LO), R6.2
unnamed: R1.1, R16.1
unnamed: D3.A, D4.C
unnamed: C17.1, IC4.1 (VI), IN5822.C
unnamed: R19.1, U$4.1 (A)
unnamed: R21.1, U$1.33 (PE2/!HWB)
unnamed: R24.2, U$5.D+
unnamed: R22.1, U$6.1 (A)
unnamed: R23.2, U$5.D-
PANNEL: D3.C, IC1.4 (IN+), J4.1, R16.2, R17.1
PWM: IC3.2 (IN), U$1.29 (PB5(ADC12))
RESET: J1.5, R20.1, RESET.1 (S), RESET.2 (S1), U$1.13 (!RESET)
RS: J6.4, U$1.27 (PD7(ADC10))
RW: J6.5, U$1.26 (PD6(ADC9))
SCK: J1.3, U$1.9 (PB1(SCK))
SWITCHNODE: C6.2, D2.C, IC3.6 (VS), L3.2, Q1.3 (S), Q4.TAB (D), R26.1, R26.2
UCAP: C20.1, U$1.6 (UCAP)
VIN: C24.1, Q1.TAB (D), R8.1, R17.2
VIN_SENSE: C9.1, R1.2, R2.2, U$1.36 (PF7(ADC7))
VOUT: C2.+, IC2.4 (IN+), L3.1, R18.1
VOUT_SENSE: C8.1, R3.1, R4.2, U$1.39 (PF4(ADC4))
XTAL1: C23.1, Q3.1, U$1.17 (XTAL1)
XTAL2: C22.1, Q3.2, U$1.16 (XTAL2)

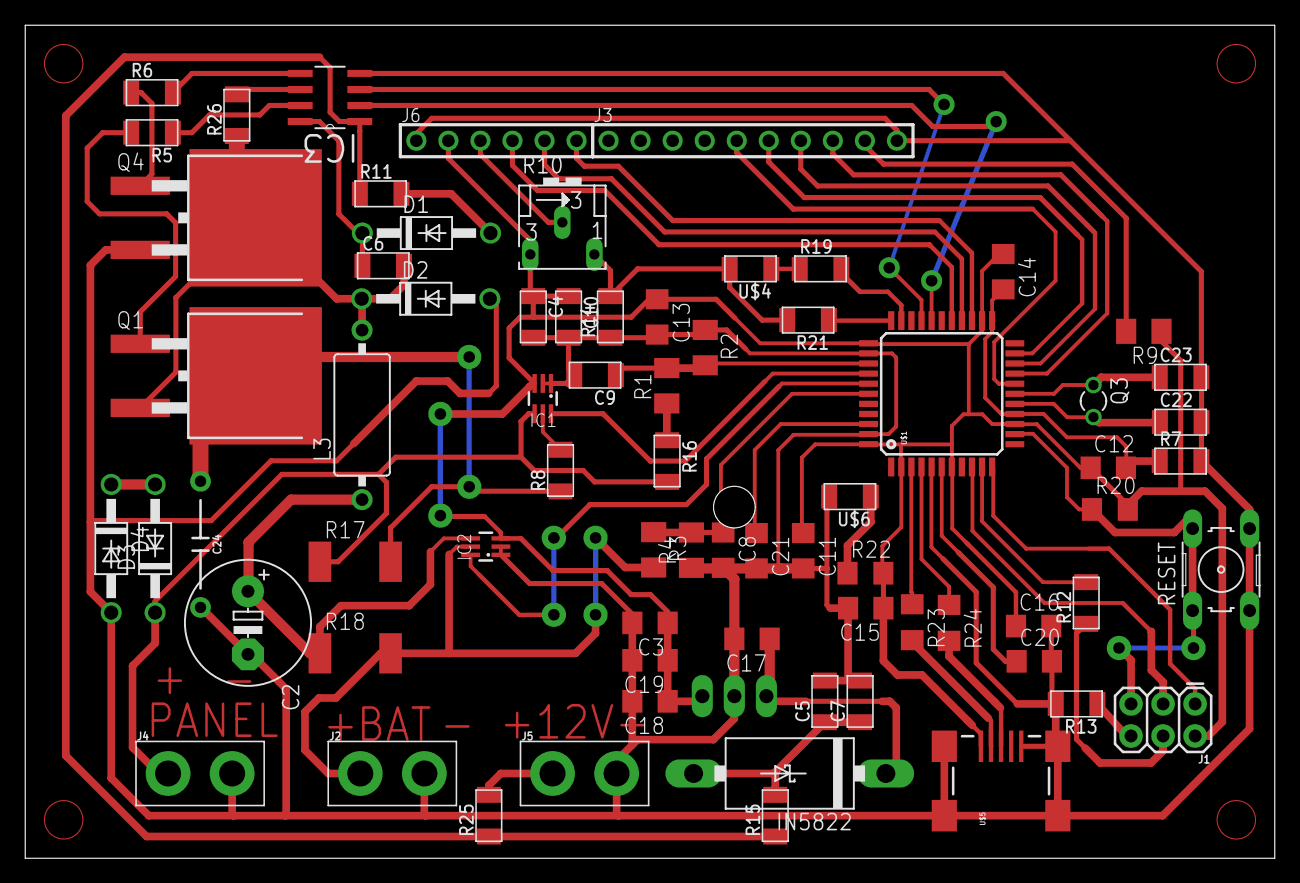
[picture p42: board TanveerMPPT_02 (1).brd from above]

Board: 2 copper layers, 99.1 x 66.0 mm, 73 parts (1 on the bottom side), 51 nets.

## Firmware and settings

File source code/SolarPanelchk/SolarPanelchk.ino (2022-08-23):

   
/*
 * Inductance Meter Shield for Arduino Uno
 * Lukas Fässler, 2015-02-11
 * See www.soldernerd.com for description, schematics, Eagle files, photos and more
 */
 
//Define ports
#define BUCK_ENABLE 10
#define BUCK_PWM 9
#define VIN A0
#define IIN A1
#define VOUT A3
#define IOUT A2
/*
//These voltages control the behaviour of our solar charger
#define ENABLE_VOLTAGE 18.0
#define DISABLE_VOLTAGE 15.0
#define INPUT_TARGET_VOLTAGE 17.0
#define OUTPUT_TARGET_VOLTAGE_LOW 13.8
#define OUTPUT_TARGET_VOLTAGE_HIGH 13.9
#define INPUT_CURRENT_LIMIT 2000.0
#define OUTPUT_CURRENT_LIMIT 3000.0
#define INPUT_CURRENT_MINIMUM 0.0
*/

#define ENABLE_VOLTAGE 15.0
#define DISABLE_VOLTAGE 13.0
#define INPUT_TARGET_VOLTAGE 14.5
#define OUTPUT_TARGET_VOLTAGE_LOW 12.0
#define OUTPUT_TARGET_VOLTAGE_HIGH 12.2
#define INPUT_CURRENT_LIMIT 2000.0
#define OUTPUT_CURRENT_LIMIT 3000.0
#define INPUT_CURRENT_MINIMUM 0.0

//Duty cycle limits
#define DUTY_CYCLE_MINIMUM 140
#define DUTY_CYCLE_MAXIMUM 240

//This compenstates for the timer running at a clock that is 64 faster than usual
#define DELAY_FACTOR 16

//The first term is a calculated or ideal multiplier
//The second term (the one close to 1.0) is an adjustment based on actual measurement
#define VIN_MULTIPLIER 0.023949 * 1.00507
#define VOUT_MULTIPLIER 0.01564 * 1.0036
#define IIN_MULTIPLIER 2.0798 * 0.99688
#define IOUT_MULTIPLIER 2.7153 *0.99202

//Set up the LCD library
#include <LiquidCrystal.h>
#define LCD_RS 6
#define LCD_RW 12
#define LCD_EN 4
#define LCD_D7 2
#define LCD_D6 0
#define LCD_D5 1
#define LCD_D4 3
LiquidCrystal lcd(LCD_RS, LCD_RW, LCD_EN, LCD_D4, LCD_D5, LCD_D6, LCD_D7);

//Some global variables
uint8_t buck_dutycycle;
float input_voltage;
float input_current;
float output_voltage;
float output_current;

//Set up the step-down DC-DC converter
void buck_setup()
{
  //Half-bridge driver enable signal
  pinMode(BUCK_ENABLE, OUTPUT);
  digitalWrite(BUCK_ENABLE, LOW);
  //Half-bridge driver PWM signal
  pinMode(BUCK_PWM, OUTPUT);
  //Fast PWM (mode 3) on OC0A (Arduino pin 6)
  TCCR1A = 0b00000010; 
  TCCR1B = 0b00000001; //Prescaler=1
  //Set dutycycle
  buck_dutycycle = 0;
  OCR1A = buck_dutycycle;    
}

//Turn on the step-down DC-DC converter 
void buck_enable()
{
  // Clock source enabled with prescaler=1
  TCCR1A &= 0b10111111;
  TCCR1A |= 0b10000000;
  //Enable signal high
  digitalWrite(BUCK_ENABLE, HIGH);
}

//Turn off the step-down DC-DC converter
void buck_disable()
{
  //Enable signal low
  digitalWrite(BUCK_ENABLE, LOW);
  // Clock source disabled
  TCCR1A &= 0b00111111;
  buck_dutycycle = 0;
}

//Set the duty-cycle for the DC-DC converter
void buck_duty(uint8_t duty)
{
  //The buck needs some off-time to keep the bootstrap capacitor of the upper FET charged
  //To ensure this we set a duty cycle clearly below 100%
  if(duty>DUTY_CYCLE_MAXIMUM)
  {
     duty = DUTY_CYCLE_MAXIMUM;
  }
  //A synchronous buck like ours can pump energy from the output to the input if the duty cycle drops below 50%
  //Eliminate this possibility by enforcing a duty cycle clearly above 50%
  if(duty<DUTY_CYCLE_MINIMUM)
  {
      duty = DUTY_CYCLE_MINIMUM;
  }
  buck_dutycycle = duty;
  OCR1A = duty;
}

//Shows measured voltages and currents on the LCD
void write_display()
{
  lcd.setCursor(0, 0);
  lcd.print("     V  ");
  lcd.setCursor(0, 0);
  lcd.print(input_voltage);
  
  lcd.setCursor(8, 0);
  lcd.print("     V  ");
  lcd.setCursor(8, 0);
  lcd.print(output_voltage);
  
  lcd.setCursor(0, 1);
  lcd.print("    mA  ");
  lcd.setCursor(0, 1);
  lcd.print((int16_t) input_current);
  
  lcd.setCursor(8, 1);
  lcd.print("    mA  ");
  lcd.setCursor(8, 1);
  lcd.print((int16_t) output_current);
}

//Measure input and output voltage and current
//Each value is measured 16 times and then averaged
void read_values()
{
  uint16_t vin_dac = 0;
  uint16_t iin_dac = 0;
  uint16_t vout_dac = 0;
  uint16_t iout_dac = 0;
  for(uint8_t j=0; j<16; ++j)
  {
    vin_dac += analogRead(VIN);
    vout_dac += analogRead(VOUT);
    iin_dac += analogRead(IIN);
    iout_dac += analogRead(IOUT);
  }
  input_voltage = vin_dac * VIN_MULTIPLIER / 16;
  output_voltage = vout_dac * VOUT_MULTIPLIER / 16;
  input_current = iin_dac * IIN_MULTIPLIER / 16;
  output_current = iout_dac * IOUT_MULTIPLIER / 16;
}

//Check if the duty cycle needs to be increased or decreased
//Also check if the DC-DC converter needs to be turned on or off
void buck_update()
{
  if(buck_dutycycle) //DC-DC converter is currently running
  {
    //Disable
    if((input_voltage<DISABLE_VOLTAGE) || (input_current<INPUT_CURRENT_MINIMUM))
    {
      buck_disable();
    }
    //Update
    else
    {
      //Reduce duty cycle
      if((input_voltage<INPUT_TARGET_VOLTAGE) || (output_voltage>OUTPUT_TARGET_VOLTAGE_HIGH) || (input_current>INPUT_CURRENT_LIMIT) || (output_current>OUTPUT_CURRENT_LIMIT))
      {
        buck_duty(buck_dutycycle-1);
      }
      //Increase duty cycle
      if((input_voltage>INPUT_TARGET_VOLTAGE) && (output_voltage<OUTPUT_TARGET_VOLTAGE_LOW)) 
      {
        buck_duty(buck_dutycycle+1);
      } 
    }
  }
  else //DC-DC converter is turned off
  {
    //Enable
    if(input_voltage>ENABLE_VOLTAGE)
    {
       buck_duty((uint8_t) (255*output_voltage/input_voltage));
       buck_enable();
    }
  }
}

//This function is called at startup
//No, nothing in this code ever calls it 
//This is Arduino-specific behaviour
void setup()
{
  //Show startup screen
  //I can't resist bragging ;-)
  lcd.begin(16, 2);
  lcd.setCursor(0, 0);
  lcd.print(" Tanveer & Habib");
  lcd.setCursor(0, 1);
  lcd.print(" SIBAU FABLAB ");
  
  //Set up DC-DC converter
  buck_setup();
  
  //Wait a bit to show the startup screen
  delay(1000*DELAY_FACTOR);
}


//This function is called forever once setup() has completed
//Again, this is Arduino-specific behaviour
void loop()
{
  for(uint8_t i=0; i<32; ++i)
  {
    read_values();
    buck_update();
    delay(10*DELAY_FACTOR);
  }
  write_display();
}

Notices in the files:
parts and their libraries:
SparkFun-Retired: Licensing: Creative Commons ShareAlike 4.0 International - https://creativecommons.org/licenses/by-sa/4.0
